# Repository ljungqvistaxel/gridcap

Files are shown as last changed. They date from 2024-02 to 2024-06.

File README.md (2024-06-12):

# Robust Positional Force Sensing Using Metal Over Capacitive Touch

This repository contains software, PCB design files, and 3D models used in the research with the title as above, as well as the collected data. The research investigates the use of metal over cap in a 2D matrix to meassure applied force at different parts of the sensor module. The data collected ad used in the research is also included in this repository.

## Used hardware and components

Gridcap module: 
- stm32f401re, charges/discharges pads and reads charging time with a 11.9 ns resolution, and sends the pads charging time over UART.
- 20x20 aluminium extrution (any standard length works, as long as its long enough).
- 220 kOhm resistor for pad charging.
- 74HC4067PW-Q100J MUX (4x), found at: https://www.mouser.se/ProductDetail/Nexperia/74HC4067PW-Q100J?qs=sPdA%252BpIfi%2F%252BXvXN1KGf9sg%3D%3D
- 0.5mm, 0.7mm or 1.0mm thich aluminium metal sheet (110mm x 110mm).
- SN74HC14N schmitt trigger, found at: https://www.digikey.se/sv/products/detail/texas-instruments/SN74HC14N/277223

Test rig:
- HX711 loadcell amplifier, found at: https://www.electrokit.com/forstarkare-for-lastceller-hx711
- 10kg rated loadcell, found at: https://www.electrokit.com/lastcell-10kg

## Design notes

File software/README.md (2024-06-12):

# Software

Naming stuff is difficult, so here is a quick overview:

## calculations/

Includes the python script used to generate graphs from the collected data. The collected data is also included here, in the form of text files in the format "[plate thickness]\_[pressure point]\_[applied force].txt". The data is stored as two rows, where the first row is the 64 individual pad capacitance readings in one snapshot, and the second row is the tare offset value for the same pads.

## loadcell/

This has an arduino IDE project to read and interpret the force applied by the test rig loadcell. The readings are sent from the microcontroller (ESP32 in our case) to the PC via UART over USB.

## stm32/

Includes the STM32 Cube IDE project for the STM32 microcontroller to measure the capacitances (time) in the sensor module and send it to the PC via UART over USB.

## uart_host/

This includes the program used for recieving and calculating the capacitances sent from the STM32 microcontroller, and shows a live view in the terminal. This program can tare, save, load and show the realtime capacitance values in its terminal interface. It even has color to help interpreting the data. Revolutionary! ;)

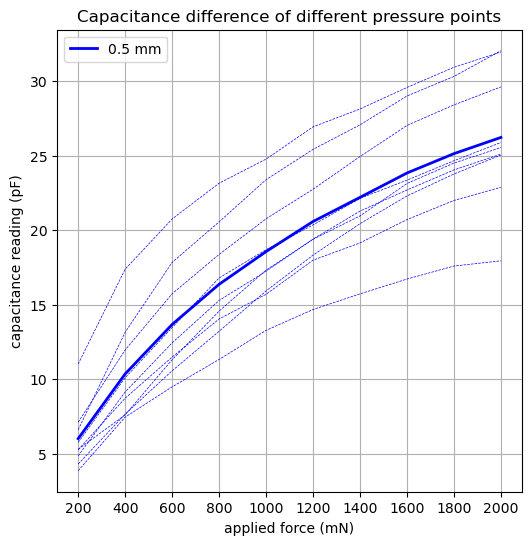
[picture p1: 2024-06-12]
software/calculations/plots/capacitance_spread_05.png

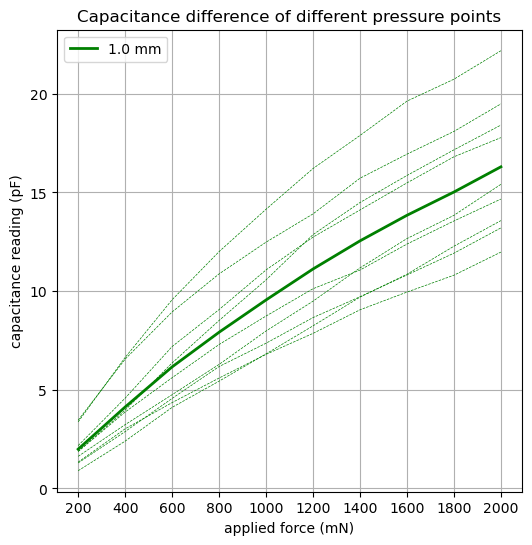
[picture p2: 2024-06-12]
software/calculations/plots/capacitance_spread_10.png

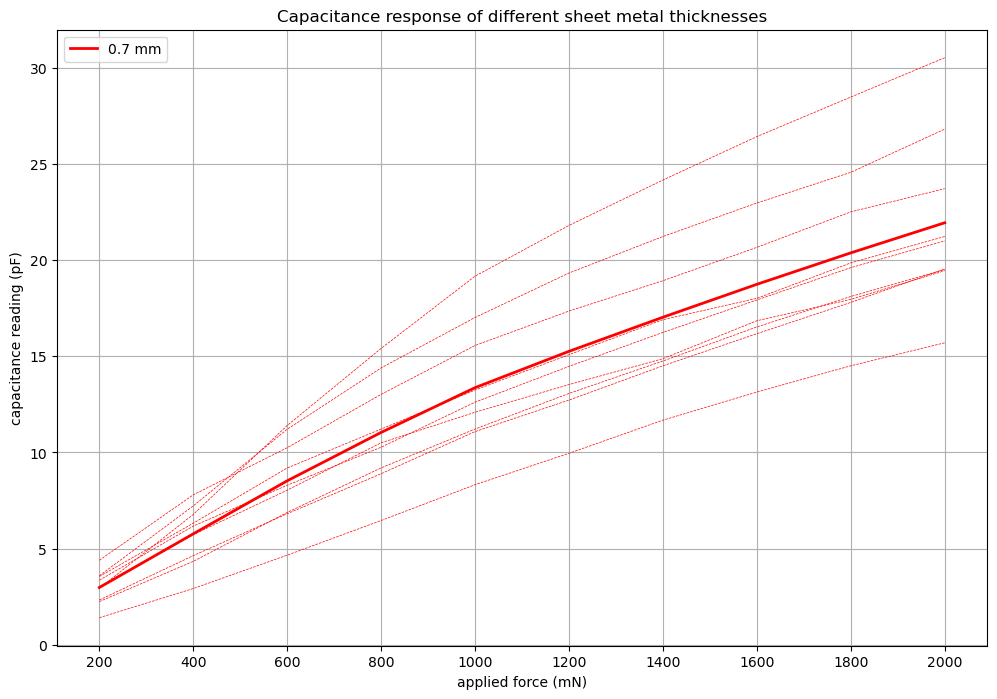
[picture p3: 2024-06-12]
software/calculations/plots/capacitance_response.png

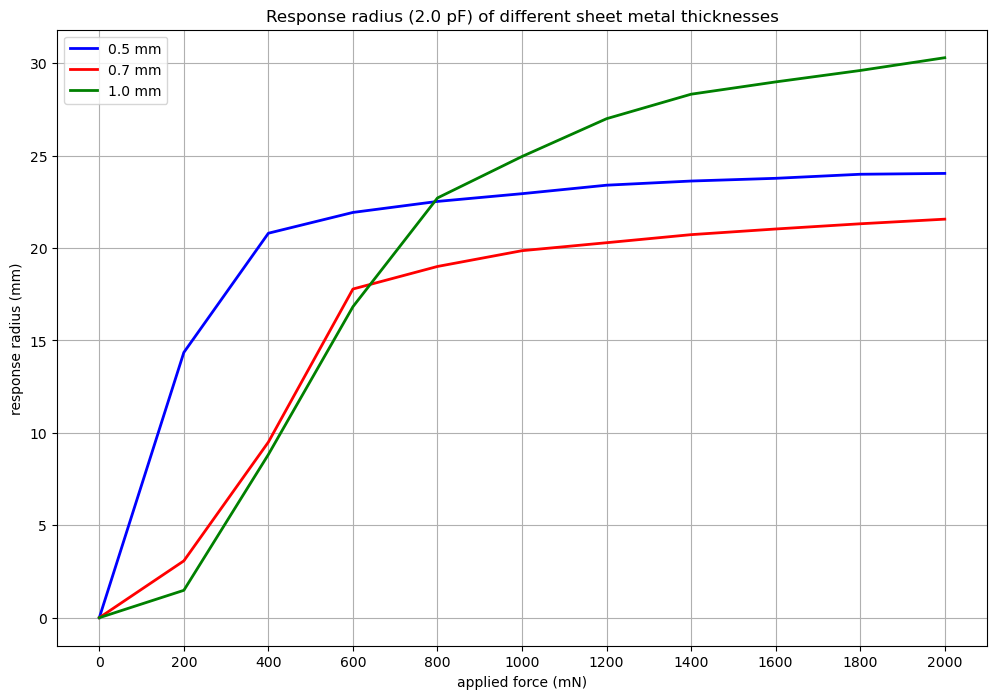
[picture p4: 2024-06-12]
software/calculations/plots/response_radius.png

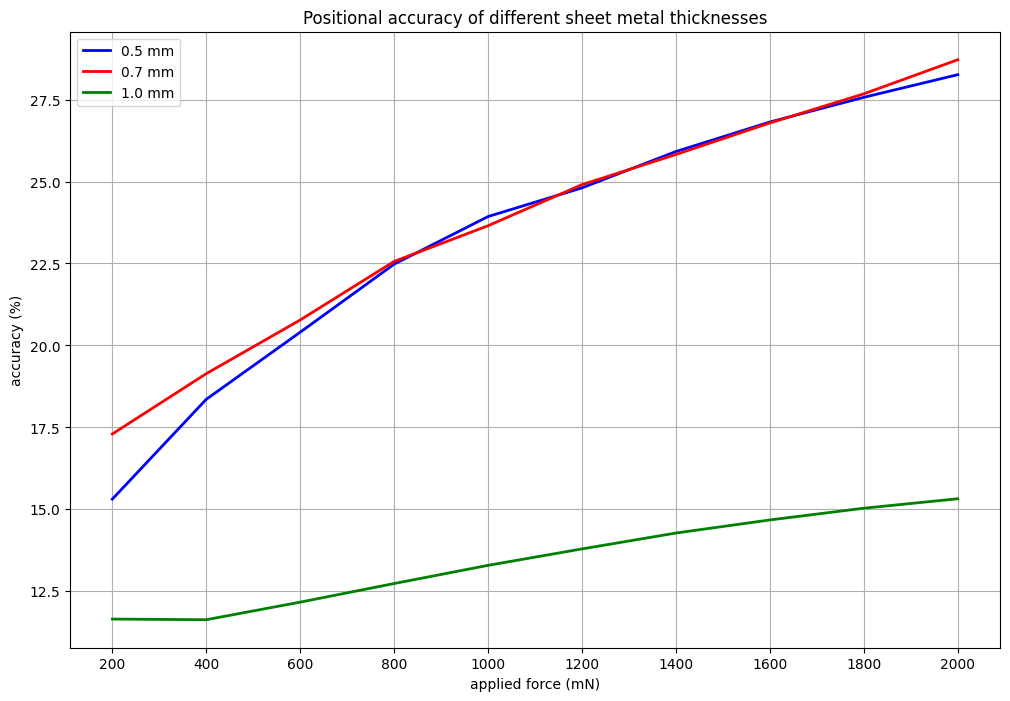
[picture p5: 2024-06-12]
software/calculations/plots/positional_accuracy.png

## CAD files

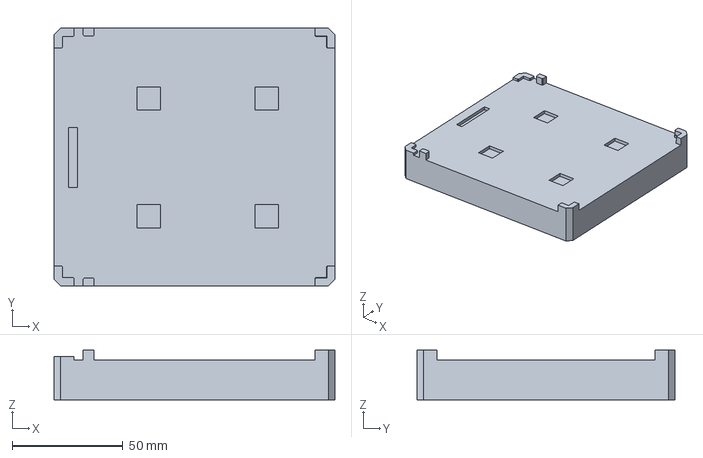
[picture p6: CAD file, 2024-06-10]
gridcap_module/step/gridcap_base.step
127.1 x 116.7 x 22.6 mm

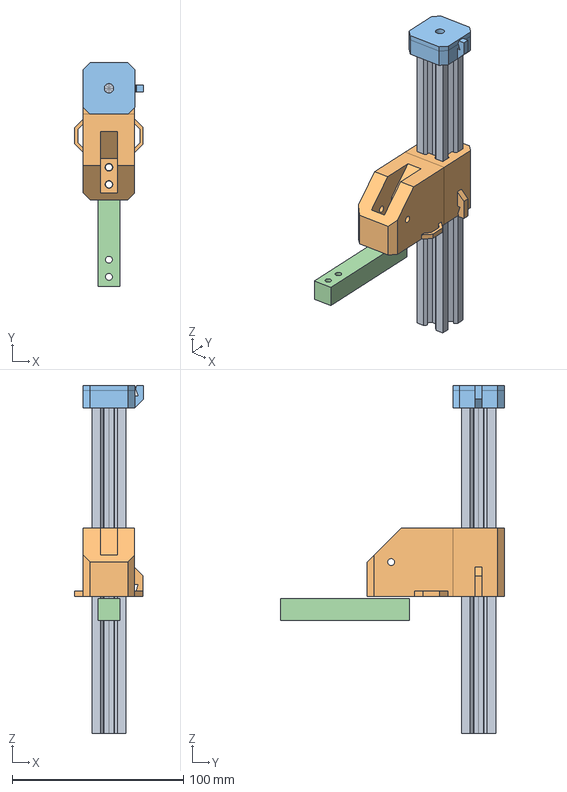
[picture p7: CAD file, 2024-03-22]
test_rig/gridcap_test_rig.FCStd
40.0 x 130.6 x 203.0 mm
z_2020
x_axis
z_top_hat
load_cell

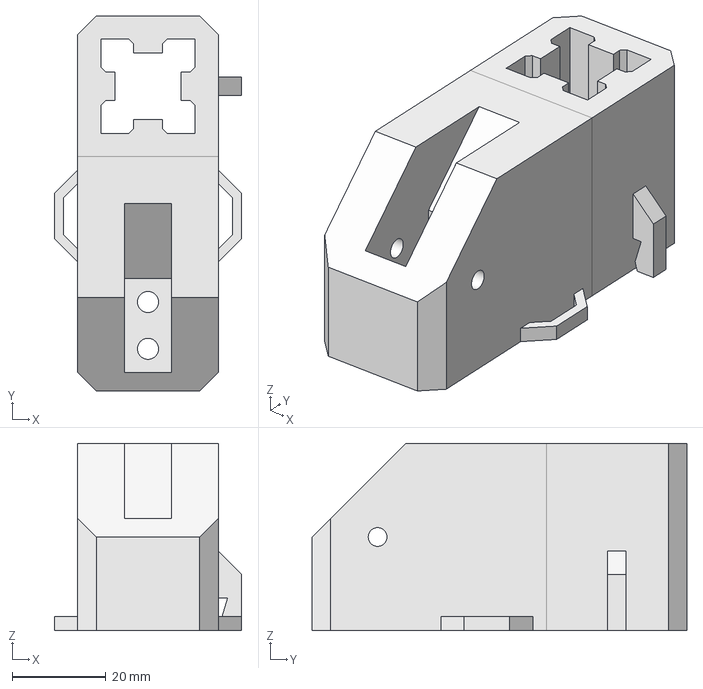
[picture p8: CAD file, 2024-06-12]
test_rig/step_and_stl/x_axis.step
40.0 x 80.0 x 40.0 mm

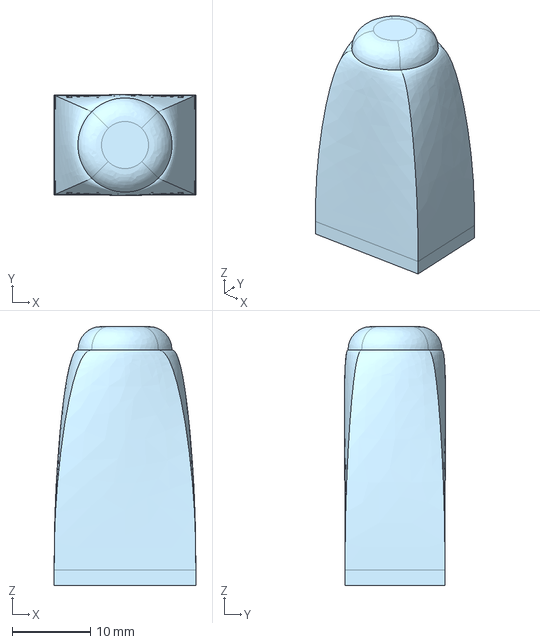
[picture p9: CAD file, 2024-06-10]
test_rig/step_and_stl/loadcell_point.step
18.0 x 12.9 x 33.0 mm

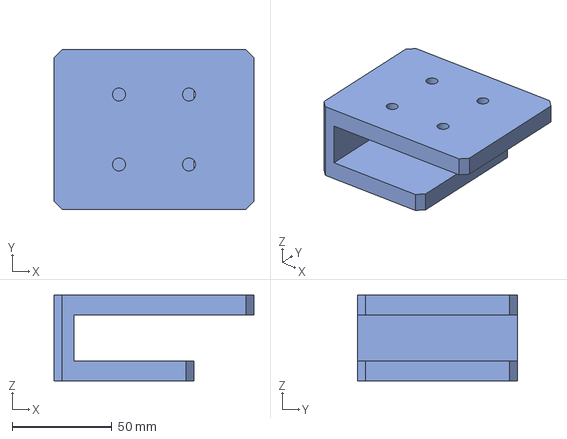
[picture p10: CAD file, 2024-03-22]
test_rig/step_and_stl/foot.step
100.0 x 80.0 x 43.0 mm

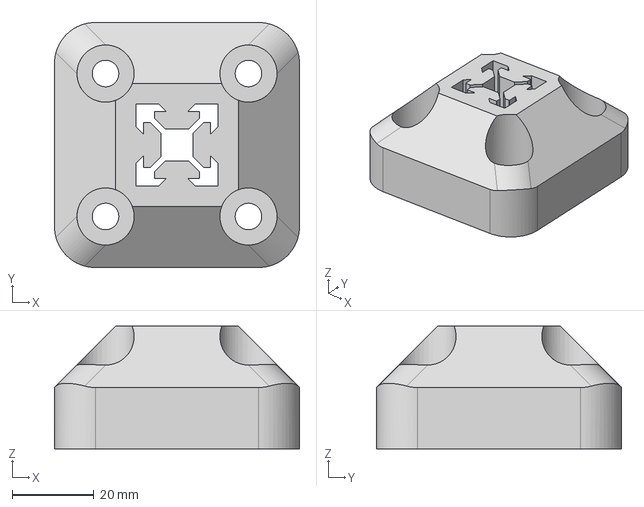
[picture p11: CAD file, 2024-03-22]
test_rig/step_and_stl/table_clamp.step
60.0 x 60.0 x 30.0 mm

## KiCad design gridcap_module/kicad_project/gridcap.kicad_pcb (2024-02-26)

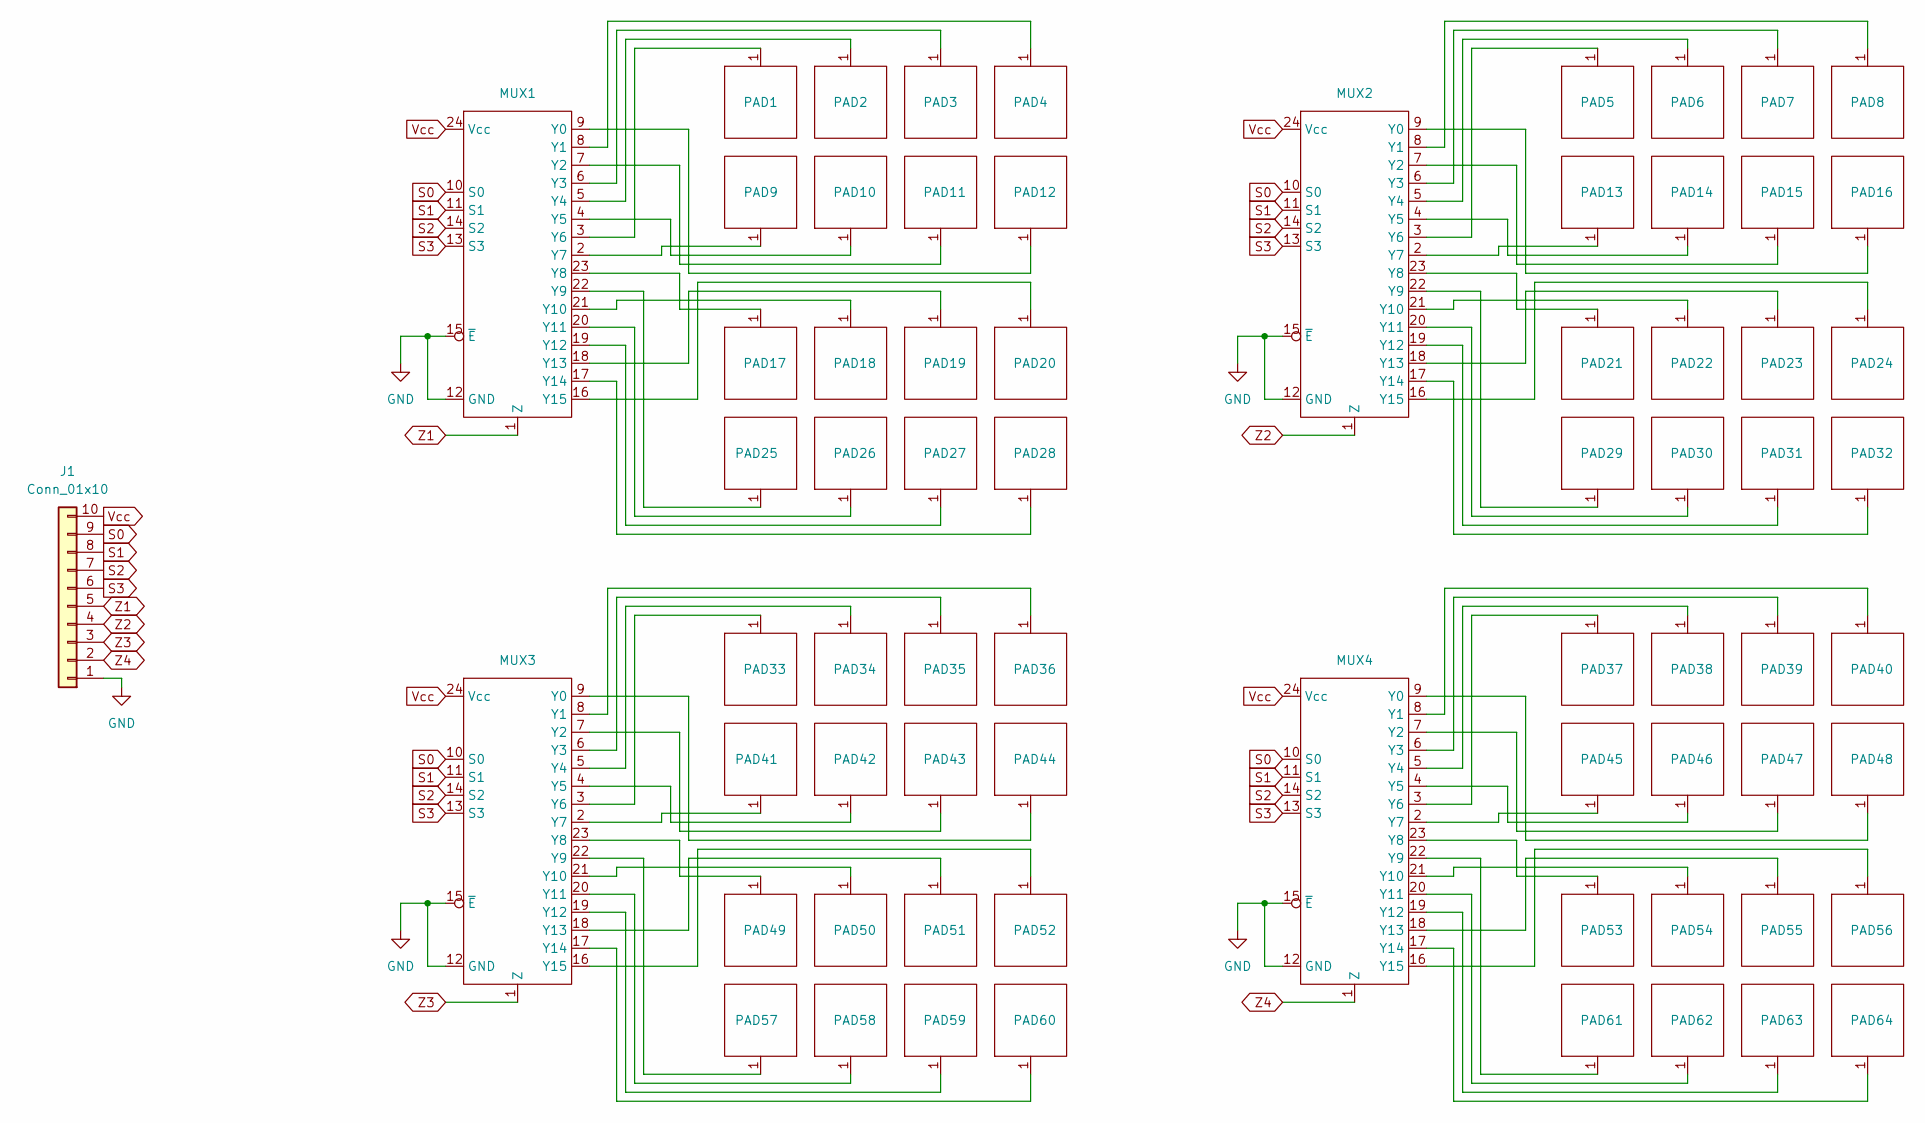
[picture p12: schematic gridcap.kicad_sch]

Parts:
J1: Conn_01x10; PinHeader_1x10_P2.54mm_Vertical
MUX1, MUX2, MUX3, MUX4: 74HC4067PW-Q100J
PAD1, PAD2, PAD3, PAD4, PAD5, PAD6, PAD7, PAD8, PAD9, PAD10, PAD11, PAD12, PAD13, PAD14, PAD15, PAD16, PAD17, PAD18, PAD19, PAD20, PAD21, PAD22, PAD23, PAD24, PAD25, PAD26, PAD27, PAD28, PAD29, PAD30, PAD31, PAD32, PAD33, PAD34, PAD35, PAD36, PAD37, PAD38, PAD39, PAD40, PAD41, PAD42, PAD43, PAD44, PAD45, PAD46, PAD47, PAD48, PAD49, PAD50, PAD51, PAD52, PAD53, PAD54, PAD55, PAD56, PAD57, PAD58, PAD59, PAD60, PAD61, PAD62, PAD63, PAD64: CAPACITOR_PAD

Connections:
GND: J1.1, MUX1.12 (GND), MUX1.15 (~E), MUX2.12 (GND), MUX2.15 (~E), MUX3.12 (GND), MUX3.15 (~E), MUX4.12 (GND), MUX4.15 (~E)
unnamed: MUX1.9 (Y0), PAD12.1
unnamed: MUX1.8 (Y1), PAD4.1
unnamed: MUX1.7 (Y2), PAD11.1
unnamed: MUX1.6 (Y3), PAD3.1
unnamed: MUX1.5 (Y4), PAD2.1
unnamed: MUX1.4 (Y5), PAD10.1
unnamed: MUX1.3 (Y6), PAD1.1
unnamed: MUX1.2 (Y7), PAD9.1
unnamed: MUX1.23 (Y8), PAD17.1
unnamed: MUX1.22 (Y9), PAD25.1
unnamed: MUX1.21 (Y10), PAD18.1
unnamed: MUX1.20 (Y11), PAD26.1
unnamed: MUX1.19 (Y12), PAD27.1
unnamed: MUX1.18 (Y13), PAD19.1
unnamed: MUX1.17 (Y14), PAD28.1
unnamed: MUX1.16 (Y15), PAD20.1
unnamed: MUX2.9 (Y0), PAD16.1
unnamed: MUX2.8 (Y1), PAD8.1
unnamed: MUX2.7 (Y2), PAD15.1
unnamed: MUX2.6 (Y3), PAD7.1
unnamed: MUX2.5 (Y4), PAD6.1
unnamed: MUX2.4 (Y5), PAD14.1
unnamed: MUX2.3 (Y6), PAD5.1
unnamed: MUX2.2 (Y7), PAD13.1
unnamed: MUX2.23 (Y8), PAD21.1
unnamed: MUX2.22 (Y9), PAD29.1
unnamed: MUX2.21 (Y10), PAD22.1
unnamed: MUX2.20 (Y11), PAD30.1
unnamed: MUX2.19 (Y12), PAD31.1
unnamed: MUX2.18 (Y13), PAD23.1
unnamed: MUX2.17 (Y14), PAD32.1
unnamed: MUX2.16 (Y15), PAD24.1
unnamed: MUX3.9 (Y0), PAD44.1
unnamed: MUX3.8 (Y1), PAD36.1
unnamed: MUX3.7 (Y2), PAD43.1
unnamed: MUX3.6 (Y3), PAD35.1
unnamed: MUX3.5 (Y4), PAD34.1
unnamed: MUX3.4 (Y5), PAD42.1
unnamed: MUX3.3 (Y6), PAD33.1
unnamed: MUX3.2 (Y7), PAD41.1
unnamed: MUX3.23 (Y8), PAD49.1
unnamed: MUX3.22 (Y9), PAD57.1
unnamed: MUX3.21 (Y10), PAD50.1
unnamed: MUX3.20 (Y11), PAD58.1
unnamed: MUX3.19 (Y12), PAD59.1
unnamed: MUX3.18 (Y13), PAD51.1
unnamed: MUX3.17 (Y14), PAD60.1
unnamed: MUX3.16 (Y15), PAD52.1
unnamed: MUX4.9 (Y0), PAD48.1
unnamed: MUX4.8 (Y1), PAD40.1
unnamed: MUX4.7 (Y2), PAD47.1
unnamed: MUX4.6 (Y3), PAD39.1
unnamed: MUX4.5 (Y4), PAD38.1
unnamed: MUX4.4 (Y5), PAD46.1
unnamed: MUX4.3 (Y6), PAD37.1
unnamed: MUX4.2 (Y7), PAD45.1
unnamed: MUX4.23 (Y8), PAD53.1
unnamed: MUX4.22 (Y9), PAD61.1
unnamed: MUX4.21 (Y10), PAD54.1
unnamed: MUX4.20 (Y11), PAD62.1
unnamed: MUX4.19 (Y12), PAD63.1
unnamed: MUX4.18 (Y13), PAD55.1
unnamed: MUX4.17 (Y14), PAD64.1
unnamed: MUX4.16 (Y15), PAD56.1
S0: J1.9, MUX1.10 (S0), MUX2.10 (S0), MUX3.10 (S0), MUX4.10 (S0)
S1: J1.8, MUX1.11 (S1), MUX2.11 (S1), MUX3.11 (S1), MUX4.11 (S1)
S2: J1.7, MUX1.14 (S2), MUX2.14 (S2), MUX3.14 (S2), MUX4.14 (S2)
S3: J1.6, MUX1.13 (S3), MUX2.13 (S3), MUX3.13 (S3), MUX4.13 (S3)
Vcc: J1.10, MUX1.24 (Vcc), MUX2.24 (Vcc), MUX3.24 (Vcc), MUX4.24 (Vcc)
Z1: J1.5, MUX1.1 (Z)
Z2: J1.4, MUX2.1 (Z)
Z3: J1.3, MUX3.1 (Z)
Z4: J1.2, MUX4.1 (Z)

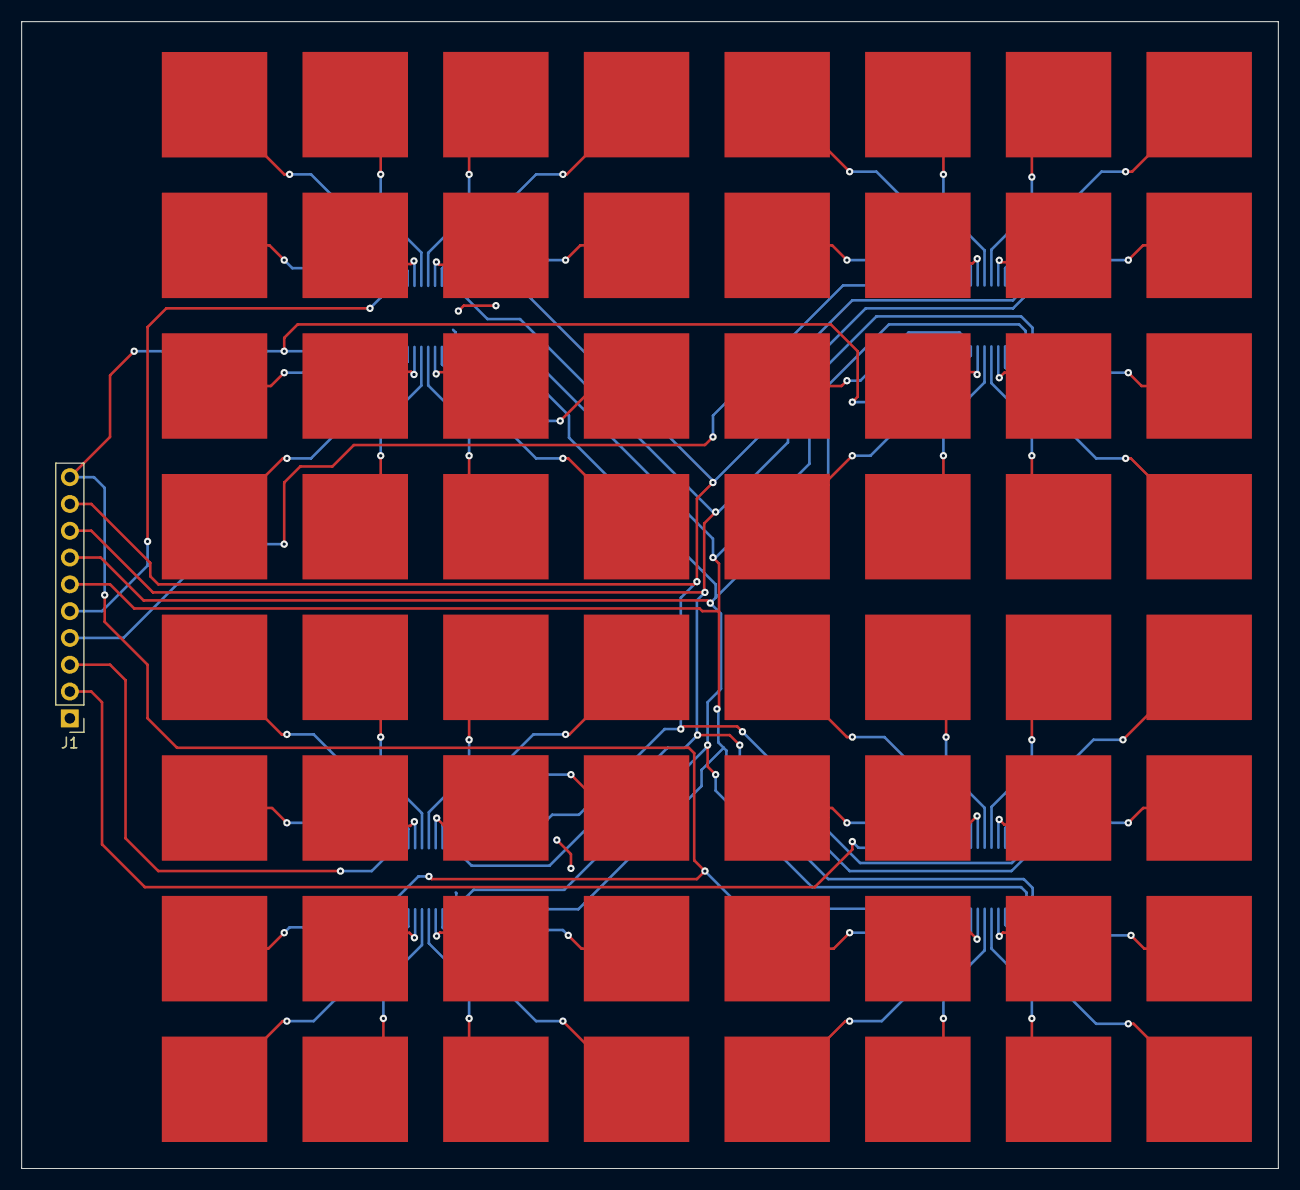
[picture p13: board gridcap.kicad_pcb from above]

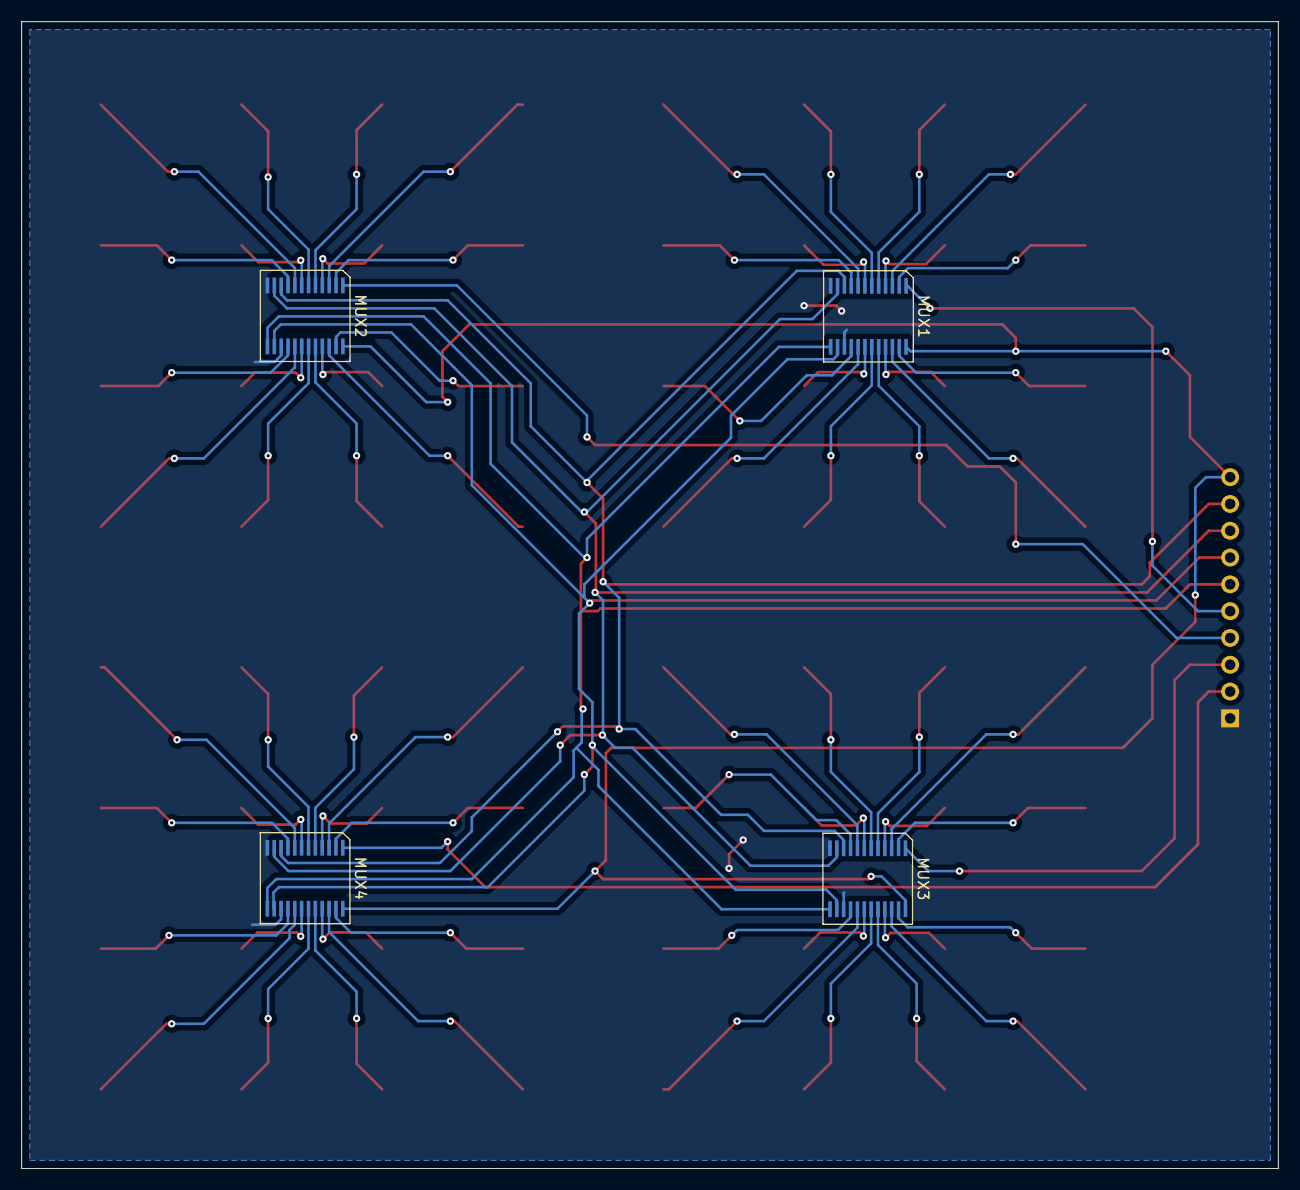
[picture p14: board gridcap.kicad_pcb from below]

Board: 2 copper layers, 119.1 x 108.7 mm, 69 parts (4 on the bottom side), 74 nets.

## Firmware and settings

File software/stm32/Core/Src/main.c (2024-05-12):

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
/* Includes ------------------------------------------------------------------*/
#include "main.h"

/* USER CODE BEGIN Includes */
#include <stdbool.h>
#include <stdio.h>
/* USER CODE END Includes */

TIM_HandleTypeDef htim5;
TIM_HandleTypeDef htim11;

UART_HandleTypeDef huart2;

/* USER CODE BEGIN PV */

bool finished_reading;


/* USER CODE END PV */

void SystemClock_Config(void);
static void MX_GPIO_Init(void);
static void MX_USART2_UART_Init(void);
static void MX_TIM5_Init(void);
static void MX_TIM11_Init(void);
/* USER CODE BEGIN 0 */

void us_delay(uint16_t us){
	__HAL_TIM_SET_COUNTER(&htim11, 0);

	while(__HAL_TIM_GET_COUNTER(&htim11)< us);
}

void start_pad_charging(uint16_t pin){
	GPIOB->ODR |= pin;
}

void stop_pad_charging(){
	GPIOB->ODR &= ~(Z0_Pin | Z1_Pin | Z2_Pin | Z3_Pin);	//STOP pad-charging pins
}

uint16_t arr_charge_time[50];
uint8_t sample_ix = 0;
void HAL_GPIO_EXTI_Callback(uint16_t GPIO_Pin){
	TIM5->CR1 &= ~(0x0001);  	//Stops timer (bit CEN in CR1 register)

	stop_pad_charging();

	if(sample_ix >= (sizeof(arr_charge_time)/sizeof(uint16_t))){
		sample_ix = 0;
		finished_reading = true;
	}
	else{
		arr_charge_time[sample_ix] = __HAL_TIM_GET_COUNTER(&htim5);
		sample_ix++;
	}


	TIM5->CNT &= (0x00000000);//Resets timer value (CNT register)
}

float convert_to_ns(uint16_t val){
	float time_const = 11.9;//11.9 ns/clk-pulse

	return (float) (val * time_const);
}

uint16_t average_reading(){
	uint8_t length = sizeof(arr_charge_time)/sizeof(uint16_t);
	float sum = 0;

	for(uint8_t i=0; i<length; i++){
		sum += convert_to_ns(arr_charge_time[i]);
	}

	return (uint16_t) (sum/length);
}

uint8_t 	pad_nbr = 0;
uint16_t 	active_charging_pin = Z0_Pin;
void switch_sch_trig(){
	static uint8_t 	arr_ix = 0;
	const uint8_t 	num_pad_groups = 4;
	uint8_t 		sch_trig_arr[] = {EXTI2_IRQn, EXTI4_IRQn, EXTI1_IRQn, EXTI0_IRQn };
	uint16_t		charging_pins[] = {Z0_Pin, Z1_Pin , Z2_Pin, Z3_Pin};

	//Disable EXTI interrupt before switching
	HAL_NVIC_DisableIRQ(sch_trig_arr[arr_ix]);


	if(arr_ix >= num_pad_groups-1){
		arr_ix = 0;
		pad_nbr = 0;
	}
	else{
		arr_ix++;
		pad_nbr++;
	}
	active_charging_pin = charging_pins[arr_ix];
	HAL_NVIC_EnableIRQ(sch_trig_arr[arr_ix]);
}

//switch used MUX and Schmitt trigger
void switch_pad(){
	static uint8_t 	mux_in_pin = 0x0;
	const uint8_t 	num_mux_pins = 0x0F;

	if(mux_in_pin >= num_mux_pins){
		mux_in_pin = 0;
		switch_sch_trig();
	}
	else {
		mux_in_pin++;
		pad_nbr++;
	}

	GPIOC->ODR &= ~(0x0F << 6);								//Reset MUX pins
	GPIOC->ODR |= mux_in_pin << 6; 							//Switch MUX output
	us_delay(100);											//Discharge connected pad.
	start_pad_charging(active_charging_pin);
	TIM5->CR1 |= 0x0001; 									//starts timer (bit CEN in CR1 register)
}

void send_UART(uint16_t charge_time){
	char tx_buff[50];
	uint8_t str_len = sprintf(tx_buff, "%d, %d\n\r", pad_nbr, charge_time);
	HAL_UART_Transmit(&huart2, (uint8_t*)tx_buff, str_len, 100);
}

/* USER CODE END 0 */

/**
  * @brief  The application entry point.
  * @retval int
  */
int main(void)
{
  /* MCU Configuration--------------------------------------------------------*/

  /* Reset of all peripherals, Initializes the Flash interface and the Systick. */
  HAL_Init();

  /* Configure the system clock */
  SystemClock_Config();

  /* Initialize all configured peripherals */
  MX_GPIO_Init();
  MX_USART2_UART_Init();
  MX_TIM5_Init();
  MX_TIM11_Init();
  /* USER CODE BEGIN 2 */
  HAL_TIM_Base_Start(&htim5);//Start 84MHz timer.
  HAL_TIM_Base_Start(&htim11); //Start timer for us-delay.

  /* USER CODE END 2 */

  /* Infinite loop */
  /* USER CODE BEGIN WHILE */
  while (1)
  {
	  //Re-charge same pad
	  if( (finished_reading == false) & ((Z0_GPIO_Port->ODR & active_charging_pin) == 0)){
		  us_delay(100);

		  start_pad_charging(active_charging_pin);
		  TIM5->CR1 |= 0x0001; //Start timer again
	  }
	  if(finished_reading){
		  uint16_t charge_time = average_reading();
		  send_UART(charge_time);
		  switch_pad(); //Starts the charging and reading of next pad, and also switch MUX output :)
		  finished_reading = false;
	  }
    /* USER CODE END WHILE */

    /* USER CODE BEGIN 3 */
  }
  /* USER CODE END 3 */
}

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


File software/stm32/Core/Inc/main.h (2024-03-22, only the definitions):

#define B1_Pin GPIO_PIN_13
#define B1_GPIO_Port GPIOC
#define sch_trigg_EXTI2_Pin GPIO_PIN_2
#define sch_trigg_EXTI2_GPIO_Port GPIOC
#define sch_trigg_EXTI2_EXTI_IRQn EXTI2_IRQn
#define sch_trigg_EXTI0_Pin GPIO_PIN_0
#define sch_trigg_EXTI0_GPIO_Port GPIOA
#define sch_trigg_EXTI0_EXTI_IRQn EXTI0_IRQn
#define sch_trigg_EXTI1_Pin GPIO_PIN_1
#define sch_trigg_EXTI1_GPIO_Port GPIOA
#define sch_trigg_EXTI1_EXTI_IRQn EXTI1_IRQn
#define USART_TX_Pin GPIO_PIN_2
#define USART_TX_GPIO_Port GPIOA
#define USART_RX_Pin GPIO_PIN_3
#define USART_RX_GPIO_Port GPIOA
#define sch_trigg_EXTI4_Pin GPIO_PIN_4
#define sch_trigg_EXTI4_GPIO_Port GPIOA
#define sch_trigg_EXTI4_EXTI_IRQn EXTI4_IRQn
#define LD2_Pin GPIO_PIN_5
#define LD2_GPIO_Port GPIOA
#define Z3_Pin GPIO_PIN_12
#define Z3_GPIO_Port GPIOB
#define Z0_Pin GPIO_PIN_13
#define Z0_GPIO_Port GPIOB
#define Z1_Pin GPIO_PIN_14
#define Z1_GPIO_Port GPIOB
#define Z2_Pin GPIO_PIN_15
#define Z2_GPIO_Port GPIOB
#define S0_Pin GPIO_PIN_6
#define S0_GPIO_Port GPIOC
#define S1_Pin GPIO_PIN_7
#define S1_GPIO_Port GPIOC
#define S2_Pin GPIO_PIN_8
#define S2_GPIO_Port GPIOC
#define S3_Pin GPIO_PIN_9
#define S3_GPIO_Port GPIOC
#define TMS_Pin GPIO_PIN_13
#define TMS_GPIO_Port GPIOA
#define TCK_Pin GPIO_PIN_14
#define TCK_GPIO_Port GPIOA
#define SWO_Pin GPIO_PIN_3
#define SWO_GPIO_Port GPIOB

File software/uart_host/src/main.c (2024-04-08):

#include <stdio.h>
#include <string.h>
#include <unistd.h>
#include <fcntl.h>
#include <errno.h>
#include <termios.h>
#include <signal.h>

#include <stdlib.h>
#include <math.h>
#include <pthread.h>

#include "uart.h"
#include "config.h"

enum program_state
{
    menu,
    live,
    exiting
};

double cap_buf[64];
double tare_buf[64];

double test_buf[64] =
{
    0.0, 0.1, 0.2, 0.3, 0.4, 0.5, 0.6, 0.7,
    0.1, 0.2, 0.7, 3.7, 5.5, 3.2, 0.4, 0.3,
    0.3, 0.5, 1.2, 10.7, 24.5, 11.3, 7.0, 5.6,
    0.1, 0.2, 0.7, 3.7, 5.5, 3.2, 0.4, 0.3,
    0.0, 0.1, 0.2, 0.3, 0.4, 0.5, 0.6, 0.7,
    0.0, 0.2, 0.2, 0.2, 0.1, 0.2, 0.3, 0.2,
    -0.1, -0.2, -0.7, -3.7, -5.5, -3.2, -0.4, -0.3,
    -24.7, -0.1, -38.5, -0.3, -3, -15, -0.6, -0.7
};

int run_threads = 1; // set to 0 to stop program safely
pthread_t uart_thread;

enum program_state program_state = menu;

void print_matrix(double* matrix, int overwrite, int tare_adjust);
void on_new_cap();
void on_uart_err();
void show_live();
void safe_exit();

void signal_handler(int s)
{
    if(program_state == live)
    {
        program_state = menu;
    }
    else if(program_state == menu)
    {
        program_state = exiting;
        safe_exit();
    }
}

int main(int argc, char** argv)
{
    printf("Good morning sir.\n");

    //print_matrix(test_buf, 0, 0);

    signal(SIGINT, signal_handler); // for catching ctrl-c

    memset(cap_buf, 0, sizeof(cap_buf)); // clear capacitances
    memset(tare_buf, 0, sizeof(tare_buf)); // clear tare buffer

    // init threads
    uart_thread_arguments utarg;
    utarg.cap_buf = &cap_buf;
    utarg.running = &run_threads;
    utarg.on_new_value = &on_new_cap;
    utarg.on_error = NULL;

    pthread_create(&uart_thread, NULL, uart_tstart, (void*)&utarg);

    printf("4488 ns = %f pF\n", cap_from_time((4488.0 * NANO))/PICO);

    char scan_buf[256];

    // menu loop
    while(program_state != exiting)
    {
        printf("\nMenu:\n live\n tare\n save\n load\n show\n reset (tare and buffers)\n exit\n\n");
        printf("gridcap > ");
        scanf("%s", scan_buf);
        if(strcmp(scan_buf, "exit") == 0)
        {
            program_state = exiting;
        }
        else if(strcmp(scan_buf, "live") == 0)
        {
            show_live();
        }
        else if(strcmp(scan_buf, "save") == 0)
        {
            printf("sheet: 0.5, point:1, force: ");
            scanf("%s", scan_buf);
            char fn[100];
            sprintf(fn, "readings/05_1_%s.txt", scan_buf);
            int f = open(fn, O_WRONLY | O_CREAT, 0666);
            if(f < 0) //error
            {
                printf("error: %s\n", strerror(errno));
                continue;
            }
            for(int i = 0; i < 64; i++)
            {
                char wb[100] = {0};
                int res = sprintf(wb, "%f ", cap_buf[i]); 
                write(f, wb, res);
            }
            write(f, "\n", 1);
            for(int i = 0; i < 64; i++)
            {
                char wb[100] = {0};
                int res = sprintf(wb, "%f ", tare_buf[i]);
                write(f, wb, res);
            }
            close(f);
        }
        else if(strcmp(scan_buf, "load") == 0)
        {
            printf("specify file from readings/ ");
            scanf("%s", scan_buf);
            char fn[150];
            sprintf(fn, "readings/%s", scan_buf);
            int f = open(fn, O_RDONLY);
            if(f < 0) //error
            {
                printf("error: %s\n", strerror(errno));
                continue;
            }
            char wb[64*15*2] = {0};
            read(f, wb, sizeof(wb));
            //printf(wb);
            char* scan_pos = wb;
            for(int i = 0; i < 64; i++)
            {
                char* space_pos = strchr(scan_pos, ' ');
                if(space_pos == NULL)
                {
                    printf("error interpreting file.\n");
                }
                else
                {
                    cap_buf[i] = atof(scan_pos);
                    scan_pos = space_pos+1;
                }
            }
            for(int i = 0; i < 64; i++)
            {
                char* space_pos = strchr(scan_pos, ' ');
                if(space_pos == NULL)
                {
                    printf("error interpreting file.\n");
                }
                else
                {
                    tare_buf[i] = atof(scan_pos);
                    scan_pos = space_pos+1;
                }
            }
            close(f);
        }
        else if(strcmp(scan_buf, "show") == 0)
        {
            print_matrix(tare_buf, 0, 0);
            printf("\n");
            print_matrix(cap_buf, 0, 0);
            printf("\n");
            print_matrix(cap_buf, 0, 1);
        }
        else if(strcmp(scan_buf, "tare") == 0)
        {
            int filled = 1;
            for(int i = 0; i < 64; i++) // check if sensor data has been received.
            {
                if(cap_buf[i] == 0) filled = 0;
            }

            if(filled == 1) // ok, do tare
            {
                memcpy(tare_buf, cap_buf, sizeof(tare_buf));
                print_matrix(tare_buf, 0, 0);
            }
            else // do not tare
            {
                printf("Not enought data to tare.\n");
            }
        }
        else if(strcmp(scan_buf, "reset") == 0)
        {
            memset(tare_buf, 0, sizeof(tare_buf)); // empty tare buffer
            memset(cap_buf, 0, sizeof(cap_buf)); // empty capacitances
            print_matrix(tare_buf, 0, 0);
            printf("\n");
            print_matrix(cap_buf, 0, 0);
        }

    }

    safe_exit();
    return 0;
}

void safe_exit()
{
    printf("exiting.\n");
    run_threads = 0;
    pthread_join(uart_thread, NULL);
    printf("Good night.\n");
    exit(0);
}

void print_matrix(double* matrix, int overwrite, int tare_adjust)
{
    if(overwrite == 1)
    {
        printf("\033[24A");
    }
    
    double val = 0;
    for(int y = 0; y < 8; y++)
    {
        for(int x = 0; x < 8; x++)
        {

            if(tare_adjust == 1)
            {
                val = matrix[y*8+x]-tare_buf[y*8+x];
            }
            else
            {
                val = matrix[y*8+x];
            }

            if(val < 0 && val > -25) // negative
            {
                printf("\033[38;5;%dm", (int)(22 + 1*((int)-val/5)));
            }
            else if(val >= 0 && val < 25) // positive
            {
                printf("\033[38;5;%dm", (int)(22 + 36*((int)val/5)));
            }
            else // out of range
            {
                printf("\033[38;5;%dm", 160);
            }

            printf("%6.1f ", val);
            printf("\033[0m");
        }
        printf("\n\n\n");
    }
}
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

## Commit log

2024-02-02 Add KiCad project and gitignore
    [gridcap.kicad_pcb, gridcap.kicad_sch]
2024-02-06 Add schematic sketches
2024-02-06 Add symbols and footprints for cap-pads and mux
2024-02-06 Add muxes and pads to schematic and begin pcb layout
    [gridcap.kicad_pcb, gridcap.kicad_sch]
2024-02-06 Add all pads to pcb
    [gridcap.kicad_pcb, gridcap.kicad_sch]
2024-02-06 Update footprint of pad
    [gridcap.kicad_pcb]
2024-02-06 Fix pad pin number
    [gridcap.kicad_pcb, gridcap.kicad_sch]
2024-02-12 Begin rewiring pads and muxes
    [gridcap.kicad_pcb, gridcap.kicad_sch]
2024-02-12 Route one mux on pcb
    [gridcap.kicad_pcb]
2024-02-12 Route all muxes to pads
    [gridcap.kicad_pcb, gridcap.kicad_sch]
2024-02-12 Route all muxes and add pcb shape
    [gridcap.kicad_pcb, gridcap.kicad_sch]
2024-02-12 Fix ground plane connections
    [gridcap.kicad_pcb]
2024-02-13 Space out tracks on pcb
    Meant to reduce signal noice between tracks
    [gridcap.kicad_pcb]
2024-02-13 Make MUX-pads longer
    [gridcap.kicad_pcb]
2024-02-13 Fix mux footprint silkscreen
    [gridcap.kicad_pcb]
2024-02-14 .gitignore plot folders and change plot settings
    [gridcap.kicad_pcb]
2024-02-24 beginning of test rig design
    [gridcap_test_rig.FCStd]
2024-02-24 add reader schematic
    [gridcap.kicad_sch, reader.kicad_sch]
2024-02-24 Rotate foot 45deg
    [gridcap_test_rig.FCStd]
2024-02-25 unknown change
    [gridcap_test_rig.FCStd]
2024-02-26 Fix pcb design to fit cogra limitations
    [gridcap.kicad_pcb]
2024-02-26 Change to fit aisler limitations and add plugin for aisler
    [gridcap.kicad_pcb]
2024-02-27 Add x-axis, z-cap and press handle
    [gridcap_test_rig.FCStd]
2024-02-27 Rename x-axis and remove unused 2020 extrusion
    [gridcap_test_rig.FCStd]
2024-02-27 Add software folder with gitignore for STM32
2024-02-27 Move stm32 gitignore to repo gitignore
2024-02-28 Add project for precalculating capacitance matrix
    calculations/ main.c and basic CMakeFiles.txt
2024-02-29 Add stm32 project
2024-02-29 Start setup adc-dma
2024-02-29 add dma and adc
2024-03-01 Add project for uart host
2024-03-01 Setup timer interrupt in cubeMx with 10kHz/100us
2024-03-04 Update mounting holes for load cell
    [foot.step, gridcap_test_rig.FCStd, table_clamp.step]
2024-03-04 Add load cell model to test rig
    [gridcap_test_rig.FCStd]
2024-03-04 Add cable routing
    [gridcap_test_rig.FCStd]
2024-03-05 Filter precalc graph
2024-03-07 Implement function to switch mux output
2024-03-07 Move ADC ch switching to its own function
2024-03-07 Fix ADC channel switching
    You apparently need to stop the dma when changing adc registers...
    [main.c]
2024-03-09 Bitshift adc values to 8-bit
    To scale it to values 0-255
2024-03-09 Add pad-nbr variable
    For sending UART :)
2024-03-10 Add UART transmition
2024-03-10 Fix bug in IT and cleanup code
    [main.c]
2024-03-11 Read UART messages from STM32
2024-03-11 Speedup ADC with 8 bit and timer
2024-03-12 Convert time to capacitance
2024-03-12 Change capacitance reading method
2024-03-12 Add menu in uart_host
2024-03-12 Read charge time :)
2024-03-12 Stable capacitance reading with one schmitt trigger
2024-03-12 Calculate capacitance from nanoseconds instead
2024-03-15 Add startup arduino project
2024-03-19 Calibrate loadcell somewhat
2024-03-19 Adjust mux switching
2024-03-19 Total charging pins from 1 to 4
2024-03-19 Add mux map for uart host
2024-03-20 Stable pad charge time readings
2024-03-20 Replace ms delays with us delays
    For faster processing!
    [gridcap.ioc, main.c]
2024-03-20 Adjust uart host constants
2024-03-21 Final calibration
2024-03-22 Change order of pin reading stm32
2024-03-22 handle uart comm in bg thread
2024-03-25 fix connection error
    connected again eventough it already was
    [main.c, uart.c]
2024-03-28 Speed up print output
2024-04-02 rename data to support multiple sample points
2024-04-08 Add empty load command for uart host
2024-04-09 Added Schmitt to schematic
    [reader.kicad_sch]
2024-04-09 Adjust resistance in schematic
    [reader.kicad_sch]
2024-05-12 Add test data and plot capacitance response
2024-05-12 update settings for capacitance calculations
2024-05-12 Change text of pos acc y axis
2024-05-21 Update reading schematic to 220kohm
    [reader.kicad_sch]
2024-06-10 Move step files and add gridcap base step
    [gridcap.kicad_pcb, gridcap.kicad_sch, gridcap_base.step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]
2024-06-12 add x-axis step file
    [x_axis.step]

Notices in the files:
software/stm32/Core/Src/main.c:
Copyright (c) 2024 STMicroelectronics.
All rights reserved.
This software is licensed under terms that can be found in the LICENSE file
